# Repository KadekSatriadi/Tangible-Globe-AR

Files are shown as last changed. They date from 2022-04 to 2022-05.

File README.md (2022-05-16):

# Tangible Globe AR

This document contains hardware requirements, instuctions, and software for recreating the AR experience of the "Tangible Globes for Data Visualisation in Augmented Reality" research project. **This project is not actively maintained nor will it be extended in near future.** 



# Hardware 
- 3D printer or Tangible globe
- Vicon/Qualisys/Optitrack system
- HoloLens 2
- 3D printed components: [Tangible-Globe-AR/tree/main/Sphere-STLs](https://github.com/KadekSatriadi/Tangible-Globe-AR/tree/main/Sphere-STLs)
- Electronic components as per the BOM on [Tangible Globe Assembly Intruction](https://github.com/KadekSatriadi/Tangible-Globe-AR/blob/main/CreatingTangibleGlobe.md)

# Software 

- Broadcast tracking data using Vicon system: [ViconToHololensFilter](https://github.com/KadekSatriadi/Tangible-Globe-AR/tree/main/Software/ViconToHololensFilter)
- HoloLens 2 application of the use cases: [Releases](https://github.com/KadekSatriadi/Tangible-Globe-AR/releases/)

# Acknolwedgement

- This research project is supported by the Postgraduate Publication Award funding from the Faculty of Information Technology, Monash University, Australia. We would like to thank all experts we interviewed, Dr René Sieber, Dr Mark A. Harrower, Mr. Jorge Wagner, and Dr Yalong Yang, for their participation and insightful feedback.
- This project uses the [Viz-Globe](https://github.com/KadekSatriadi/Viz-Globe) plugin. 
- OSC plugin: https://github.com/Iam1337/extOSC

# Export citation

Satriadi, K.A., Smiley, J., Ens, B., Cordeil, M., Czauderna, T., Lee, B., Yang, Y., Dwyer, T., Jenny, B. 2021. Tangible Globes for Data Visualisation in Augmented Reality. In CHI ’22: ACM Conference on Human Factors in Computing Systems, April 30 - May 5 2022, New Orleans, USA

```
@inproceedings{satriadi2022tangibleglobear,
author = {Satriadi, Kadek Ananta and Smiley, Jim and Ens, Barrett and Cordeil, Maxime and Czauderna, Tobias and  Lee, Benjamin and Yang, Ying and Dwyer, Tim and Jenny, Bernhard},
title = {Tangible Globes for Data Visualisation in Augmented Reality},
year = {2022},
publisher = {Association for Computing Machinery},
address = {New York, NY, USA},
doi = {https://doi.org/10.1145/3491102.3517715},
booktitle = {Proceedings of the 2022 CHI Conference on Human Factors in Computing Systems},
location = {New Orleans, USA},
series = {CHI '22}
}

```

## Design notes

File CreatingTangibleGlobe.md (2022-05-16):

## Tangible Globe Assembly Instruction

3D print the three .stl files - recommended in a black PLA. The led mount object will need to be duplicated in your 3d printer program in order to print 10x items. For precision, keep in mind that various 3d printers may introduce unpredictable shrinkage, so minor trial and error resizing may be needed for tight tolerances. 

Gently deburr the equator and connector mounts if necessary.

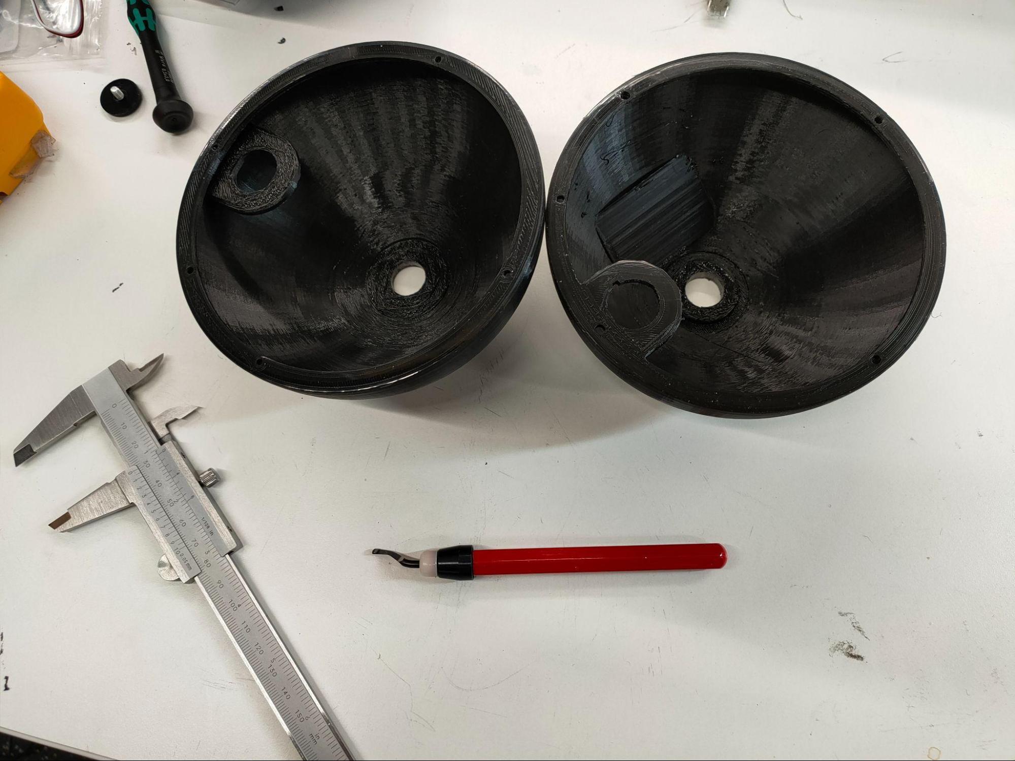
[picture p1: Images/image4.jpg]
image_hemispheres


On each hemisphere, with a 5mm bit, drill five asymmetrically spaced holes, avoiding the poles, and the bottom area of the Southern hemisphere, where the electronics sit. Aim for scalene triangles, with unique distances apart, yet obtaining even coverage over the globe. These holes were  deliberately left off the model to avoid identical objects, and for ease of printing, however feel free to modify the stl files, but supports will be needed, and holes will most likely need to be sized at 5.5mm to adjust for shrinkage. Deburr the holes. 

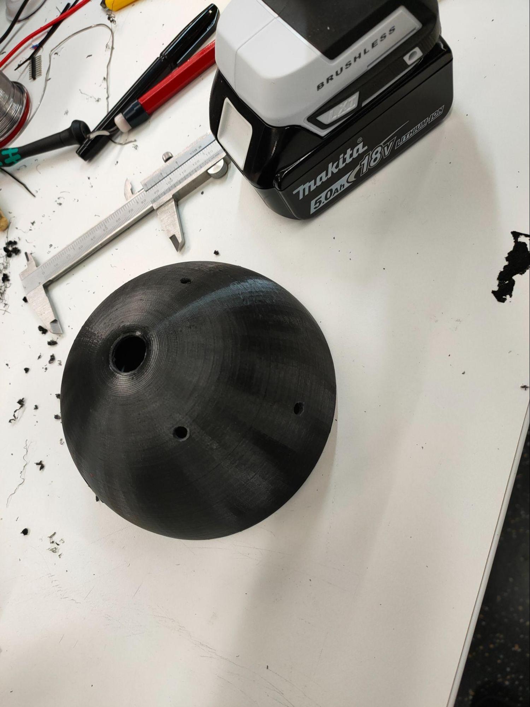
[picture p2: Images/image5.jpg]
image_deburr_holes


If tight tolerance has been achieved on the led mounts, the IR leds should firmly slot into the flat side of these. Bend Led legs flat.  Solder resistors in series with the anodes. Then glue each led assembly -  with cathodes facing towards their respective poles -  into the drilled globe holes, a small amount of superglue onto the curved printed surface only will suffice. 

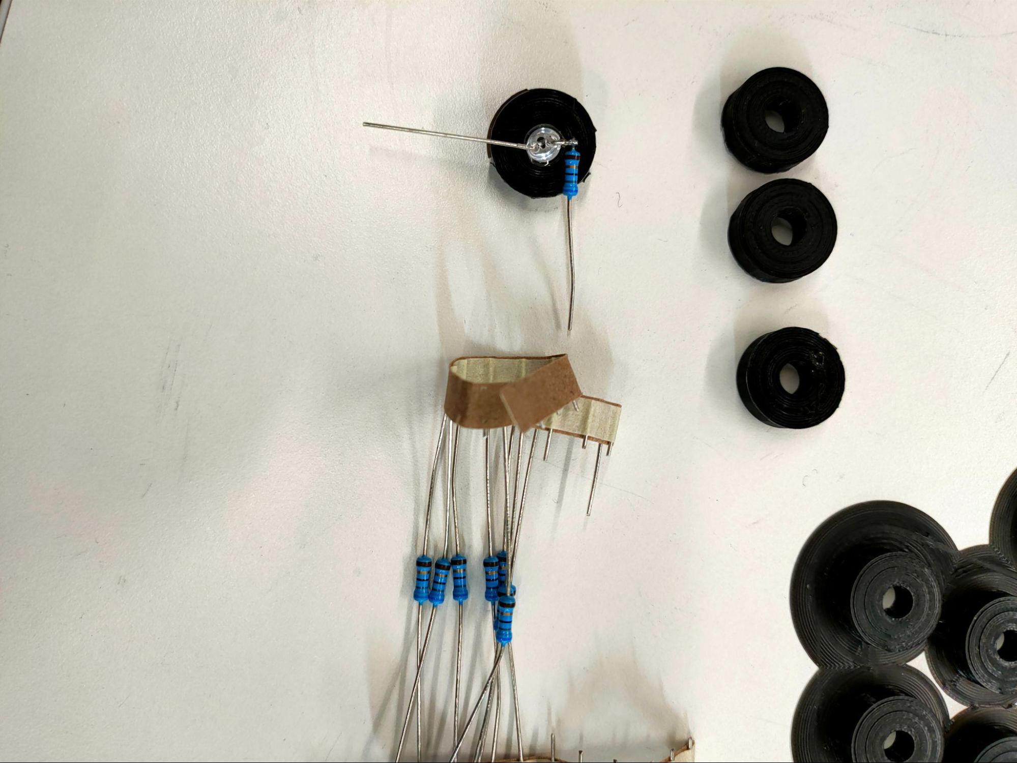
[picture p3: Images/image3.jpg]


Wire the leds in parallel on each hemisphere, I suggest a spiral using 0.7mm bare tinned wire for ground connections.  Install switches, and connectors.

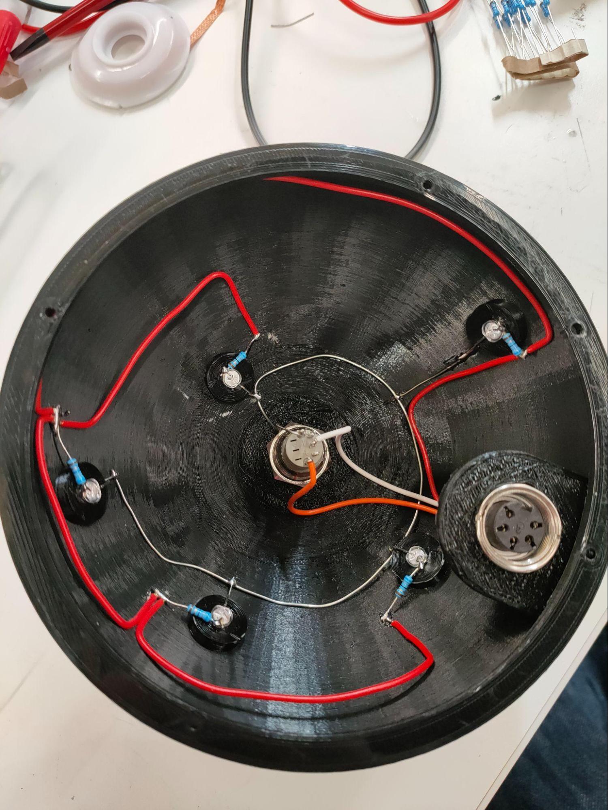
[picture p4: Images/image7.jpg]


Install matching headers on esp32 board and relay board.Program the esp32, and then using alternating layers of strong adhesive velcro, mount the esp32 to the  battery, and then to the flat surface on the interior of the southern hemisphere. 
Wire up the accelerometer, and relay board. Accelerometer can be modified to fit underneath the relay board by cutting off the unused end of the PCB. 



On the northern hemisphere, use M3 screws, removing the heads,  or M3 rod to create alignment guides.



Hemispheres should snap together tightly over the m3 thread, but use thin double sided tape to secure. The above picture shows the aftermath of superglue instead, which was a poor choice.
Wireless Charging coil glues into the bottom of the 3d printed charging stand. Supply with 9v.
Print, cut and apply the gores as shown in this excellent video: https://vimeo.com/90740474
Dark maps look great in the hololens, however will block the Leds if too dark.
The poles will glue over the buttons nicely, wait for the gores to dry before gently pressing the buttons, allowing the paper to gently flex.

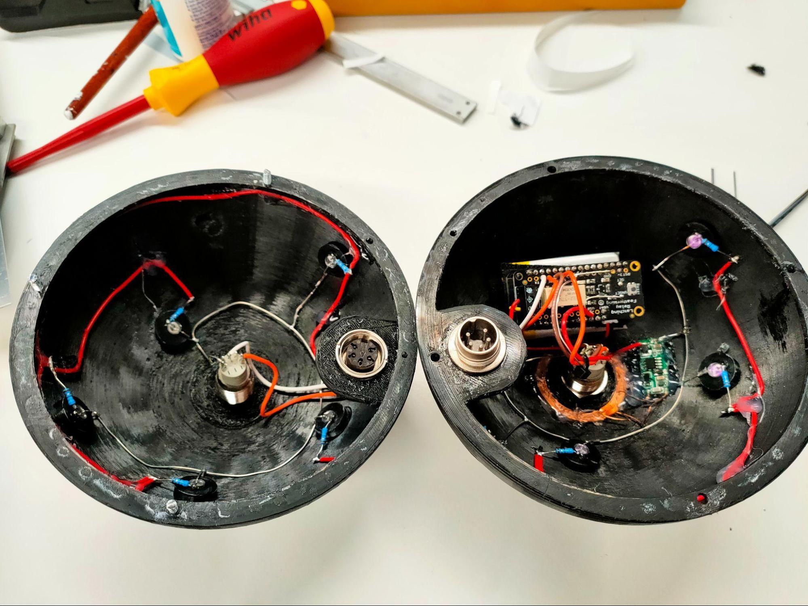
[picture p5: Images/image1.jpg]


## BOM 

| Qty. | Item | Type | Sample link |
|---|---|---|---|
| 10 | Infrared Emitter, 850 nm, 35 °, T-1 3/4 (5mm), 85 mW/Sr | 15400585A3590 | https://au.element14.com/wurth-elektronik/15400585a3590/infrared-emitter-850nm-t-1-3-4/dp/2764989 |
| 10 | Through hole resistors 1/4W, 56 - 68 Ohm | | |
| 2 | 16mm illuminated pushbutton - choice of colours | | https://core-electronics.com.au/metal-pushbutton-momentary-16mm-white.html |
| 1 | Accelerometer | ADXL335 | https://core-electronics.com.au/adxl335-triple-axis-accelerometer-gy-61.html |
| 1 | ESP32 Feather microcontroller board | ADA3405 | https://core-electronics.com.au/adafruit-huzzah32-esp32-feather-board.html |
| 1 | latching relay board | ADA2923 | https://core-electronics.com.au/adafruit-latching-mini-relay-featherwing.html |
| 1 | LiPo battery 3.7v 1200mAH | 1200mah no longer available? | https://core-electronics.com.au/polymer-lithium-ion-battery-1000mah-38458.html |
| 1 | Inductive charging set | ADA1407 | https://core-electronics.com.au/inductive-charging-set-5v-at-500ma-max.html |
| 1 | 5pin panel mount connector | T 3363 100 | |
| 1 | 5pin panel mount connector | T 3362 000 | |
| 1 | 9v power supply | | |
| | M3 screws or threaded rod | | |
| | misc wiring | | |

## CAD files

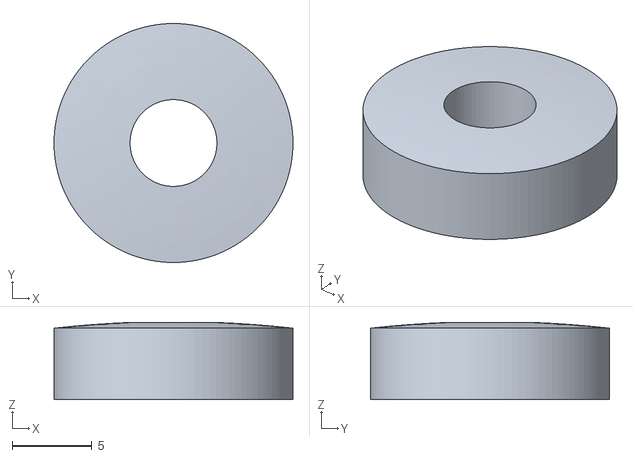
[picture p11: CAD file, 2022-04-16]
Sphere-STLs/LedMount4point45mm.stl
15.0 x 15.0 x 4.84

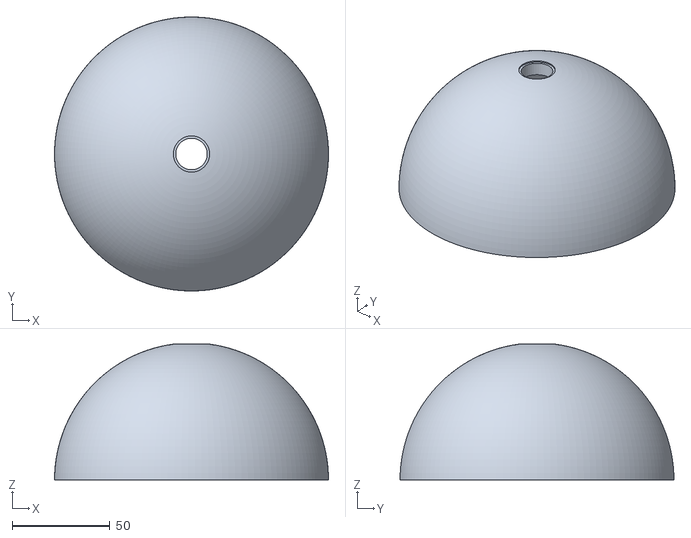
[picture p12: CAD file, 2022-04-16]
Sphere-STLs/MiniGlobeBase.stl
140.0 x 140.0 x 69.4

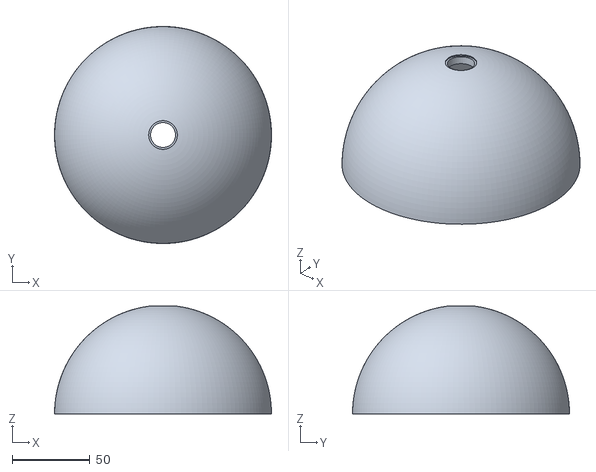
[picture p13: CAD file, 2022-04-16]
Sphere-STLs/MiniGlobeTopWithConnector.stl
140.0 x 140.0 x 69.4

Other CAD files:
Sphere-STLs/LedMount.stl
